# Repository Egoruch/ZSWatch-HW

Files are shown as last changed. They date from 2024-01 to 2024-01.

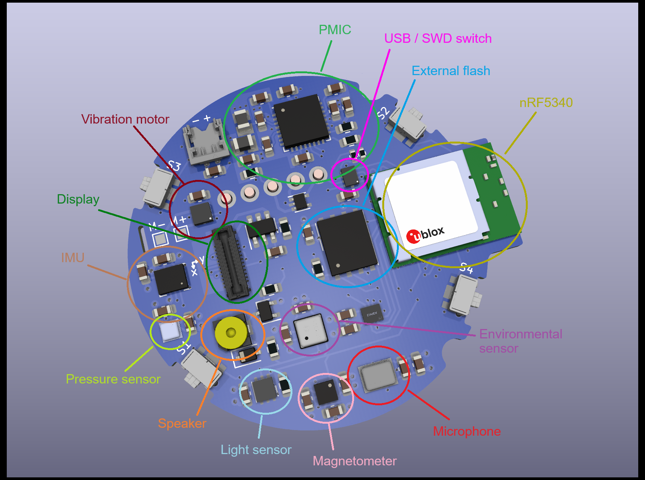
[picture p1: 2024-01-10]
docs/images/Overview.png

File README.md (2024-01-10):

# ZSWatch Hardware

## Table of Contents

- [ZSWatch Hardware](#zswatch-hardware)
  - [Table of Contents](#table-of-contents)
  - [About](#about)
  - [Directory structure](#directory-structure)
  - [Maintainer](#maintainer)

## About

Hardware repository for the [ZSWatch](https://github.com/jakkra/ZSWatch).

PCB Top side

Please check the [wiki](https://github.com/jakkra/ZSWatch/wiki) for more information about the project.

## Directory structure

- `cad`: 3D model of the complete PCB
- `docs`: All kind of project documentation like schematics, BOM, etc.
  - `drawings`: 2D drawings for subcomponents, etc.
  - `images`
- `production`: Production files for the PCB
  - `PCBWay`: Ordering instructions and production files ready for ordering at [PCBWay](https://www.pcbway.com/)
- `project`: KiCad project for the PCB

## Maintainer

- [Daniel Kampert](mailto:daniel.kameprt@kampis-elektroecke.de)
- [Jakob Krantz](mail@jakobkrantz.se)

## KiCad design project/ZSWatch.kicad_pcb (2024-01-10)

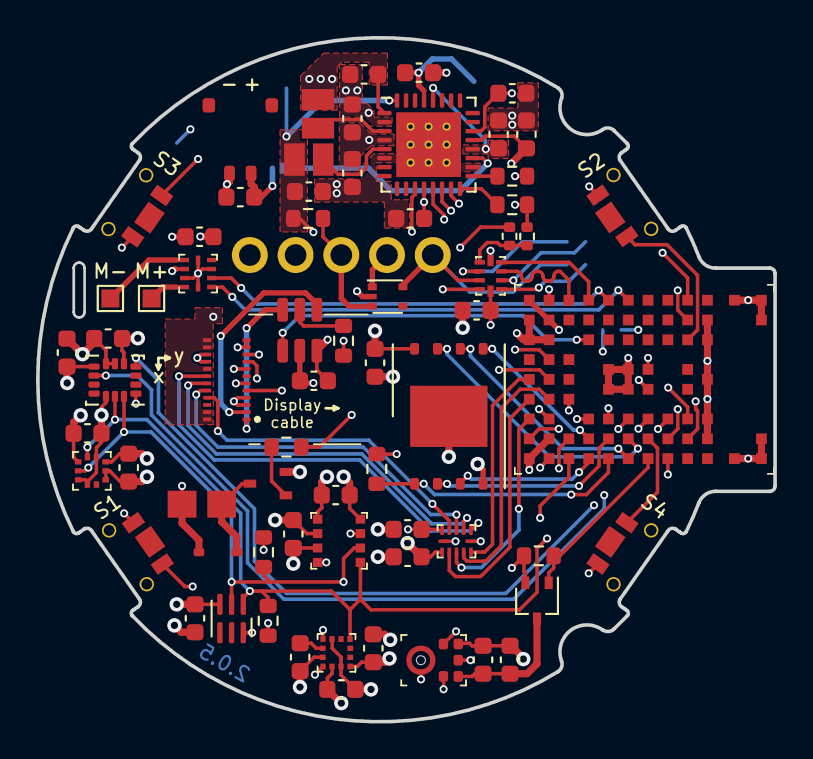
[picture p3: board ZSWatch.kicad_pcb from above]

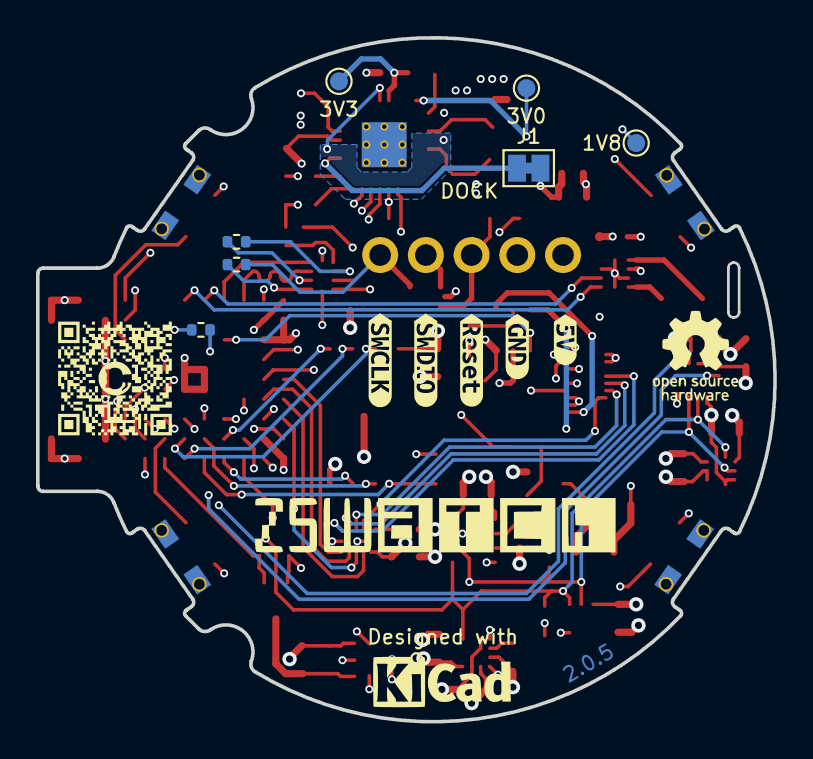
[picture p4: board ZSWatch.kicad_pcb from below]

Board: 4 copper layers, 41.0 x 38.0 mm, 80 parts (13 on the bottom side), 69 nets.

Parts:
BZ1: Buzzer; CMT-322-65-SMT-TR
C1, C10, C21, C23: 1u; C_0603_1608Metric
C2, C11, C12, C13, C14, C15, C18, C19, C20, C22, C25, C26, C27, C28: 100n; C_0603_1608Metric
C3: 2u2; C_0603_1608Metric
C4, C5, C6, C7, C8, C9, C17: 10u; C_0603_1608Metric
C16: 220n; C_0603_1608Metric
C24: 200p; C_0603_1608Metric
D1: BAS316; D_SOD-323
IC1: nPM1300-QEXX; QFN-32-1EP_5x5mm_P0.5mm_EP3.6x3.6mm_ThermalVias
IC2: APDS-9306-065; Broadcom_DFN-6_2x2mm_P0.65mm
IC3: BMI270; LGA-14_3x2.5mm_P0.5mm_LayoutBorder3x4y
IC4: BMP581; Bosch_LGA-10_2x2mm_P0.5mm_ClockwisePinNumbering
IC5: LIS2MDLTR; LGA-12_2x2mm_P0.5mm
IC6: BME688; Bosch_LGA-8_3x3mm_P0.8mm_ClockwisePinNumbering
IC7: ESDALC6V1W5; SOT-665
IC8: FAN5622SX; TSOT-23-6
IC9: S25FS512SAGNFI010; WSON-8-1EP_8x6mm_P1.27mm_EP3.4x4.3mm
IC10: TS3USB221A; UQFN-10_1.55x2.05mm_P0.5mm
IC11: NTS0104GU12; XQFN-12-1.7x2mm_P0.4mm
IC12: DRV2603RUNT; WQFN-10_2x2mm_P0.5mm
J1: SolderJumper-2_P1.3mm_Bridged_Pad1.0x1.5mm
L1, L2: 2u2; L_0806_2016
M1: NORA-B106
MK1: SPH0645LM4H-B; SPH0645LM4H-6_3.5x2.65mm
Q1: BC817W; SOT-323_SC-70
Q3: DMG1013UW-7; SOT-323_SC-70
R1: 47k; R_0603_1608Metric
R2, R14: 150k; R_0603_1608Metric
R3: 12k; R_0603_1608Metric
R4, R8: 100k; R_0603_1608Metric
R5, R6: 4k7; R_0603_1608Metric
R7: 180R; R_0603_1608Metric
R9, R10, R11, R12, R13: 0R; R_0402_1005Metric
S1, S2, S3, S4: TL6340AF160Q; TL6340AF160Q_Modified
TP1: 3V3; TestPoint_Pad_D1.0mm
TP2: 1V8; TestPoint_Pad_D1.0mm
TP3: 3V0; TestPoint_Pad_D1.0mm
X1: BATTERY; 78171-0002
X2: DOCK; RD90_LZH0230529-004_DJ-5PIN_PH2_54
X3: GC9A01A_CST816S; ER-CON0.4-24P
X4: M+; TestPoint_Pad_1.0x1.0mm
X5: M-; TestPoint_Pad_1.0x1.0mm
kibuzzard-656642B5: G***; kibuzzard-656642B5
kibuzzard-656642E4: G***; kibuzzard-656642E4
kibuzzard-65664307: G***; kibuzzard-65664307
kibuzzard-65664337: G***; kibuzzard-65664337
kibuzzard-65664342: G***; kibuzzard-65664342

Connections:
+1V8: C2.1, C7.1, C11.1, C12.1, C13.2, C14.2, C15.1, C17.1, C18.1, C19.1, C20.2, C22.1, C26.1, IC1.1 (VOUT1), IC1.12 (VDDIO), IC2.3 (VDD), IC3.5 (VDDIO), IC3.8 (VDD), IC3.12 (CSB), IC4.1 (VDDIO), IC4.5 (SDO), IC4.6 (CSB), IC4.10 (VDD), IC5.3 (CS), IC5.9 (VDD), IC5.10 (VDDIO), IC6.2 (CSB), IC6.6 (VDDIO), IC6.8 (VDD), IC9.8 (VCC), IC11.1 (VCCA), L2.1, M1.A7 (VDD), M1.A8 (VDDH), M1.B7 (VDD), Q3.2 (S), R4.1, R5.2, R6.2, R14.2, TP2.1, X3.11 (VDDIO), X3.12 (VDDIO)
+3V0: BZ1.1 (-), C5.1, C25.1, D1.1 (K), IC1.32 (VOUT2), IC10.10 (VDD), L1.1, R8.1, R10.2, TP3.1
/MCU/BMI270-INT1: IC3.4 (INT1), M1.G5 (P1.08)
/MCU/BMI270-INT2: IC3.9 (INT2), M1.G4 (P1.04)
/MCU/LIS2MDL_INT: IC5.7 (INT/DRDY), M1.H1 (P0.24)
/MCU/MIC_BCLK: M1.G3 (P0.25/AIN4), MK1.4 (BCLK)
/MCU/MIC_DATA: M1.F3 (P0.19), MK1.6 (DATA)
/MCU/MIC_EN: M1.G1 (P1.06), Q3.1 (G), R14.1
/MCU/MIC_SEL: M1.E3 (P0.21), MK1.2 (SEL)
/MCU/PMIC-INT: IC1.11 (GPIO4), M1.J8 (P0.28/AIN7)
/MCU/SENSOR-SCL: IC1.14 (SCL), IC2.1 (SCL), IC3.13 (SCK), IC4.2 (SCK), IC5.1 (SCL/SPC), IC6.4 (SCK), M1.D3 (P0.07/AIN3), R5.1
/MCU/SENSOR-SDA: IC1.13 (SDA), IC2.2 (SDA), IC3.14 (SDI), IC4.4 (SDI), IC5.4 (SDA/SDI/SDO), IC6.3 (SDI), M1.C1 (P0.10/TRACEDATA[1]), R6.1
/MCU/VBAT: C3.1, C28.1, IC12.7 (VDD), J1.1 (A), X1.1
/MCU/VBUS-MCU: C10.1, IC1.22 (VBUSOUT), M1.B9 (VBUS)
/MCU/VDD-Display: C8.1, C21.2, C27.1, IC1.29 (LSOUT1/VOUTLDO1), IC8.3 (VIN), IC11.11 (VCCB), TP1.1, X3.13 (VDD), X3.14 (VDD), X3.17 (CTP-VDD), X3.23 (LEDA2), X3.24 (LEDA1)
BTN_1: M1.H3 (P0.27/AIN6), S1.1
BTN_2: M1.J7 (P1.10), S2.2
BTN_3: IC1.15 (SHPHLD), M1.J9 (P0.31), S3.2
BTN_4: M1.G2 (P0.26/AIN5), S4.1
BUZZER: M1.B6 (P0.01/XL2), R7.1
D+/SWDCLK: IC7.5 (I/04), IC10.8 (D+), R12.2, X2.1
D-/SWDIO: IC7.1 (I/01), IC10.7 (D-), R11.2, X2.2
DISPLAY_BLK: IC8.1 (CTRL), M1.D7 (P0.23)
DISPLAY_CLK: M1.B1 (P0.08/TRACEDATA[3]), X3.8 (SCL)
DISPLAY_CS: M1.A2 (P0.12/TRACECLK), X3.9 (CS)
DISPLAY_DATA: M1.C2 (P0.09/TRACEDATA[2]), X3.6 (SDI/SDA)
DISPLAY_DC: M1.B3 (P0.11/TRACEDATA[0]), X3.5 (RS/DC)
DISPLAY_EN: IC11.12 (OE), M1.C4 (P1.01)
DISPLAY_RST: M1.B5 (P0.03/NFC2), X3.10 (RESET)
DRV_VIB_EN: IC12.1 (EN), M1.F9 (P1.15)
DRV_VIB_PWM: IC12.2 (PWM), M1.E9 (P1.05)
GND: C1.2, C2.2, C3.2, C4.2, C5.2, C6.2, C7.2, C8.2, C9.2, C10.2, C11.2, C12.2, C13.1, C14.1, C15.2, C16.2, C17.2, C18.2, C19.2, C20.1, C21.1, C22.2, C23.1, C24.1, C25.2, C26.2, C27.2, C28.2, IC1.2 (PVSS1), IC1.6 (PVSS2), IC1.18 (NTC), IC1.33 (AVSS), IC2.6 (GND), IC3.1 (SDO), IC3.6 (GND), IC3.7 (GND), IC4.3 (GND), IC4.8 (GND), IC4.9 (GND), IC5.6 (GND), IC5.8 (GND), IC6.1 (GND), IC6.5 (SDO), IC6.7 (GND), IC7.2 (GND), IC8.2 (GND), IC9.4 (GND), IC9.9 (EP), IC10.5 (GND), IC11.6 (GND), IC12.3 (LRA/~ERM), IC12.5 (GND), IC12.8 (GND), IC12.10 (GND), M1.A1 (GND), M1.A9 (GND), M1.B2 (GND), M1.B8 (GND), M1.E4 (GND), M1.E5 (GND), M1.F4 (GND), M1.F5 (GND), M1.K2 (GND), M1.K3 (GND), M1.K5 (GND), M1.K7 (GND), M1.K8 (GND), M1.L1 (GND), M1.L9 (GND), M1.M1 (GND), M1.M2 (GND), M1.M8 (GND), M1.M9 (GND), MK1.1 (WS), MK1.3 (GND), Q1.2 (E), R1.1, R2.1, R3.1, R13.2, S1.2, S2.1, S3.1, S4.2, X1.2, X2.4, X3.3 (GND), X3.4 (GND), X3.15 (GND), X3.16 (GND)
LEDK1: IC8.6 (LED1), X3.1 (LEDK-1)
LEDK2: IC8.4 (LED2), X3.2 (LEDK-2)
MCU_D_N: IC10.4 (2D-), M1.D9 (D-)
MCU_D_P: IC10.3 (2D+), M1.C9 (D+)
MCU_SWDCLK: IC10.1 (1D+), M1.J2 (SWDCLK), R12.1
MCU_SWDIO: IC10.2 (1D-), M1.H2 (SWDIO), R11.1
unnamed: BZ1.2 (+), D1.2 (A), Q1.3 (C)
unnamed: IC1.3 (SW1), L2.2
unnamed: IC1.5 (SW2), L1.2
unnamed: IC1.19 (VBAT), J1.2 (B)
unnamed: IC1.17 (VSET1), R1.2
unnamed: IC1.16 (VSET2), R2.2
unnamed: C16.1, IC5.5 (C1)
unnamed: IC8.5 (ISET), R3.2
unnamed: IC10.6 (~OE), R10.1, R13.1
unnamed: IC11.10 (B1), X3.21 (CTP-INT)
unnamed: IC11.9 (B2), X3.20 (CTP-SCL)
unnamed: IC11.8 (B3), X3.19 (CTP-SDA)
unnamed: IC11.7 (B4), X3.18 (CTP-RST)
unnamed: IC12.9 (OUT+), X4.1
unnamed: IC12.6 (OUT-), X5.1
unnamed: C23.2, C24.2, MK1.5 (VDD), Q3.3 (D)
unnamed: Q1.1 (B), R7.2
QSPI_CLK: IC9.6 (SCK), M1.F1 (P0.17/QSPI_CLK)
QSPI_CS: IC9.1 (~CS), M1.E1 (P0.18/QSPI_CS), R4.2
QSPI_IO0: IC9.5 (SI(I/O0)), M1.D2 (P0.13/QSPI[0])
QSPI_IO1: IC9.2 (SO(I/O1)), M1.E2 (P0.14/QSPI[1])
QSPI_IO2: IC9.3 (~WP(I/O2)), M1.D1 (P0.15/QSPI[2])
QSPI_IO3: IC9.7 (~HOLD(I/O3)), M1.F2 (P0.16/QSPI[3])
RESETn: M1.J3 (~RESET), R9.2
SEL_SWD: IC7.3 (I/02), IC10.9 (S), R8.2, R9.1, X2.3
TOUCH_INT: IC11.2 (A1), M1.A4 (P1.00)
TOUCH_RST: IC11.5 (A4), M1.A5 (P0.20)
TOUCH_SCL: IC11.3 (A2), M1.A3 (P1.03/I2C)
TOUCH_SDA: IC11.4 (A3), M1.B4 (P1.02/I2C)
VBUS: C1.1, IC1.21 (VBUS), X2.5
VSYS: C4.1, C6.1, C9.1, IC1.4 (PVDD), IC1.20 (VSYS), IC1.28 (LSIN1/VINLDO1)

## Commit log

2024-01-10 test: sch changes
    [ZSWatch.kicad_sch]
2024-01-10 test: fron another repo
    [BOM.xls, MCU.kicad_sch, Power.kicad_sch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]
